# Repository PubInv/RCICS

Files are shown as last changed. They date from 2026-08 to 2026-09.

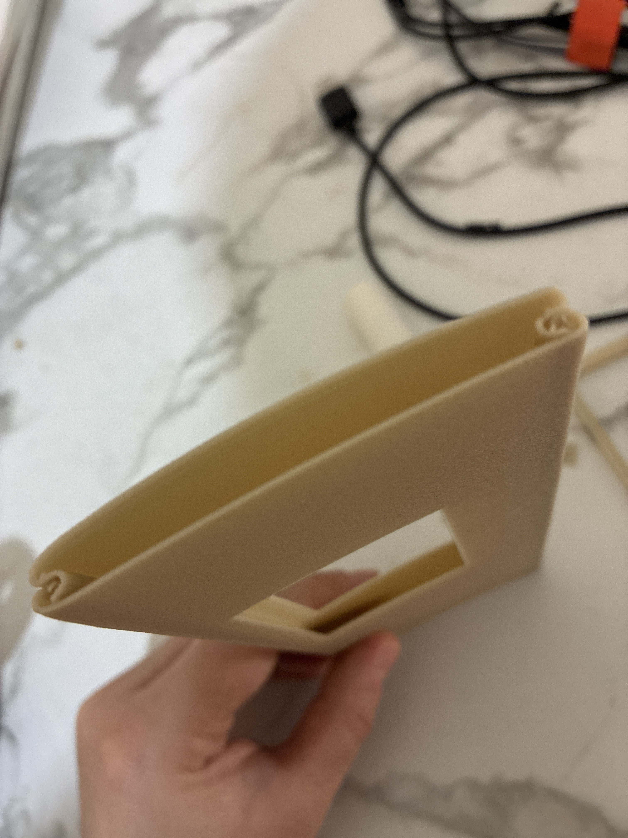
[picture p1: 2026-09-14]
designs/august-2026/CAD/img/print260905/2.jpg

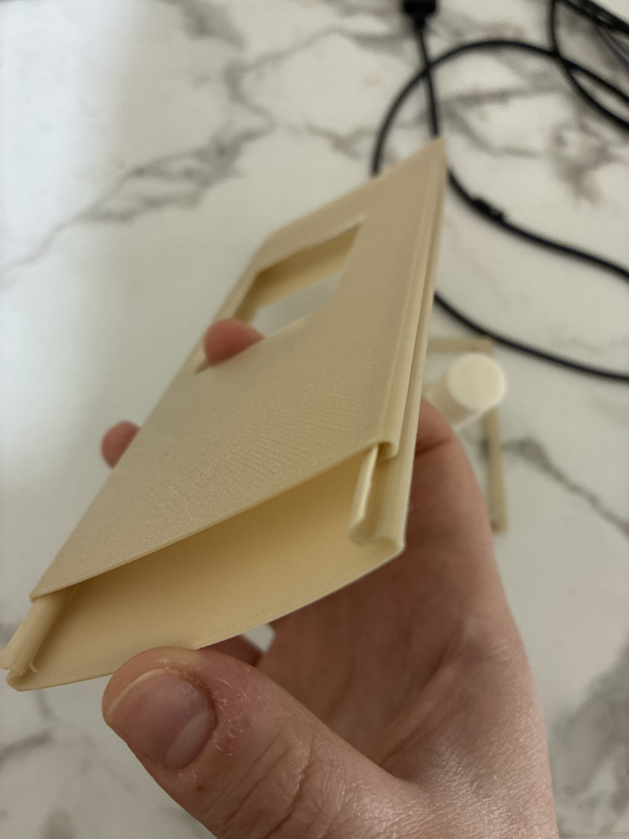
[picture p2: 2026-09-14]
designs/august-2026/CAD/img/print260905/IMG_7551.jpg

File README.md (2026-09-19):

# Rapid Contact Isolation Containment System — RCICS

RCICS is an open source effort to develop a locally fabricable
door-replacement assembly for temporary contact/droplet isolation spaces.

> RCICS is not an airborne-isolation or negative-pressure system.
> The current designs have not been validated or approved for clinical use.

## Current development

The active design iteration is:

- [September 2026 design](designs/september-2026/README.md)

## Historical snapshots

- August 2026 concept: `v1.0.0_AugustDesign`
- [August design summary](designs/august-2026/AgustDesignNotes.md)
 
## Project documentation

- [WHO questions](QUESTIONS_WHO.md)
- [Clinical questions](QUESTIONS_CLINICAL.md)
- [Requirements](docs/requirements/)
- [Design decisions](docs/decisions/)
- [Meeting notes](docs/meeting-notes/)
- [Research](docs/research/)

## Contribution workflow

1. Open or select an issue.
2. Create a branch for the change.
3. Update the design and associated documentation.
4. Open a pull request.
5. Obtain technical review before merging.

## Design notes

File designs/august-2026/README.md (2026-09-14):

# RCICS August 2026 Concept Design

> Historical concept-design snapshot. This design has not been validated
> or approved for clinical deployment.

The complete August design snapshot is preserved in the Git tag:

`august-design-v0.1`

This iteration included:

- Repurposed door concept.
- Viewing-panel concept.
- Medical-line pass-through concept.
- PVC material-transfer chamber.
- L-shaped structural support.
- Initial FreeCAD models and technical drawings.
- Scaled components for 3D printing.

## Important limitations

Dimensions and material selections were provisional.

Known unresolved matters included:

- Transfer-chamber diameter.
- Port diameter and clinical allocation.
- Viewing-panel material and thickness.
- Fastener specification.
- Door-construction differences.
- Gasket and sealing details.
- Prototype validation.

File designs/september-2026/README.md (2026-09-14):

# RCICS September 2026 Design

## Status

Active concept-development iteration.

> This design remains unvalidated and is not approved for clinical use.
> RCICS is intended for contact/droplet isolation support and is not an
> airborne-isolation or negative-pressure system.

## Objective

Develop a locally fabricable door assembly incorporating:

- A rigid viewing panel.
- Medical-line pass-through ports.
- A material-transfer chamber.
- Line strain relief.
- Sealable unused openings.
- Non-porous, disinfectant-compatible surfaces.
- Safe entry and emergency egress.

## Starting design direction

- Repurposed door as the assembly base.
- Plexiglas viewing panel.
- L-beam aluminum mounting frame.
- Gasketed panel-to-door interface.
- At least three medical-line pass-through ports.
- Separate material-transfer chamber.
- Replaceable or sealable port inserts.
- Local fabrication using commonly available tools.

## Provisional assumptions

- Three approximately 7 cm line ports.
- Silicone bungs or grommets, subject to availability.
- PVC-based port solution as fallback.
- Metal door preferred for the initial prototype.

## Open decisions

- Final number and diameter of ports.
- Clinical function assigned to each port.
- Plexiglas thickness.
- Transfer-chamber diameter and length.
- Gasket material.
- Fastener type, depth, and spacing.
- Mounting approach for metal and wooden doors.
- Line strain-relief mechanism.
- Prototype-build location.
- Validation procedure.

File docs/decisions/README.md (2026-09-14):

# RCICS Design Decision Log

This directory records important design decisions separately from meeting
notes and informal discussions.

| ID | Decision | Status | Owner |
|---|---|---|---|
| DEC-001 | Final line-port diameter | Open | Technical lead |
| DEC-002 | Transfer-chamber diameter | Open | Technical lead |
| DEC-003 | Viewing-panel thickness | Open | Design team |
| DEC-004 | Port-insert technology | Open | Courtney / field team |
| DEC-005 | Metal versus wooden door details | Open | Design team |

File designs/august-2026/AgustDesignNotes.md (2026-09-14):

# RCICS
Rapid Contact Isolation Containment System (RCICS)

This is an attempt to design a system for Ebola infection containment which can be 
placed inside a door frame to support the Ebola crisis.

This is an offshoot of Michael Min's FlexContain project of Helpful Engineering, which
pre-existed the current Bundibugyo strain outbreak of Ebola in the Congo (and a conatined outbreak in Uganda.)

## Basic Ideas

1. Either shim something into the frame, or modify the door.
2. Create a "port module" which is standardized that can be used in any door-like structure.
3. Create a "tubing module" that goes near the hinge side that puts minimum motion on tubes passing through the door as it is opened or closed.

## The August Design



An initial design what we can call the "August Design" is depicted above. It features:
1. Standard doors with a modular port cut 18" wide and 24" high in the door.
2. A polyethylene sheeting as a view window, preferable "4 mill" (0.004 inches or 0.1016 millimeters), which is widely available.
3. A "transfer chamber" made of 4" PVC tubing with two doors (end caps) which are never opened at the same time. A ["van stone" flange](https://www.pvcfittingsonline.com/blogs/resource-center/all-about-that-flange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) may be an effective way to seal this against the poly sheeting as it pierces it.
4. L-shaped metal bracket is mounted between the bottom bar and the transfer chamber to support the chamber’s weight and reduce mechanical strain. Metal retaining wires pass through the bracket and wrap around the transfer chamber to secure it firmly in place.
5. A medical tubing port with "cross-cut straw holes" and a vertical bend to create a torturous path for droplets. This port is on the hinge side to limit pulling on tubes.
6. Sheeting clamps consisting of rigid aluminum L-shaped beams to compress the poly sheeting against a gasket.
7. A "flange" (or two) which seal the circular holes of the transfer chamber and the tubing port.

Dimensions of the full design:
1. Portal width: 18"
2. Portal height: 24"
3. Transfer chamber diameter: 8" O.D.
4. Transfer chamber length: 18"
5. Medical tubing O.D.: 1"
6. Medical tubing length: 18" (but bent or shaped into strong vertical shape).

## Photos of the Model

On August 29th, 2026, Rob made a 1/8th scale model depicted below based on ideas generated with Nagham, Courtney, and Jack. It is of course imperfect, but approximately accurately:
1. We commend "L"-beam extruded aluminum strips rather that flat bars as shown in the model.
2. The model has no gasket, but one is advised.
3. There is a bracket cut of foamcore holding up the transfer chamber; this would be a metal shelf bracket at scale.
4. The polyethelyne sheet is cut from a food storage baggie; a thicker material would be avisedly used.
5. The 8" PVC in the full-scale design is simulated with 1" PVC.
6. A drinking straw simulates the 1" PVC that forms the "medical tube port" for thin tubes, such as oxygen.
7. The door is to scale, but steel doors would likely be better than wooden doors. If a wooden door is used, it should be covered in plastic sheeting.
8. This model does not discuss the sealing of the "sweep" or the "jam" of the door.

   Note that the window if off-center; it should be placed closer to the hinge side of the door, so that opening and closing the door creates minimal motion of the tubes in the tube port.

This is a view of the "Clean side", where nurses may observe and interact with the patient.
As would be typical, both "doors" of the transfer chamber are closed (these are the PVC caps.)



The infectious/patient side is depicted below. Strips of extruded metal are used to compress the polyethylene
sheeting against a gasket pressed against the door with sheet metal screws drilled through 
the L-beam, gasket, polyethylene, and metal of the door.



A close-up of screws into the metal strip pressing the sheeting against the door (there is no gasket in this model).





A close-up of the "medical tubing port". Note a wire (brown cord) can be use for strain relief. This tube is intentional "bent" or curved so that droplets have to go upward against gravity to get through the tube. (This tube will also have "cross-cut straw holes" to mostly block fluid droplets.)



The Transfer chamber is sealed through the sheeting with a compressing fitting or "flange". In 1" PVC, this is a threaded screw, but in larger sized is would likely be slip-on bushing or bolted "flanges".





A side view, showing the patient side on the left and the clean side on the right.



The transfer chamber has two caps or "doors". These are simple PVC camps with a retaining wire, so that 
when they are removed the don't fall onto the floor.



The same retaining method is on the clean side.



Although the two open doors shouldn't be open at the same time, this shows that the chamber is open.



MountingTC






Here's a similar model: https://cdn.who.int/media/docs/default-source/documents/emergencies/initiate-idtm-technical-report_20231016.pdf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

This is a WHO design for an isolation module for containment...it contains all the medical equipment that was passed through, so based on the document, I made a list of every single pass-through required: 

- Respiratory Port: oxygen, ventilator, CPAP, BiPAP, HFNC/HFNO tubing
- Patient Fluid Port: IV infusion, medication, feeding, nasogastric, urinary drainage tubing
- Suction Port: suction tubing for mucus, blood, saliva, phlegm, and other fluids
- Monitoring and Power Port: ECG, SpO2, temperature, EtCO2, blood-pressure cables, power and data cables. 

And at least 1 pass-through opening to transfer large materials, i.e., meals. (As mentioned on GitHub - the transfer chamber). For the ports, it should also be sealable when not in use...and include a securement feature. Based on all of that, I found a few commercial ports that are used for similar reasons, but we have to modify them.

1) 1.20" ID - Ext. Length. Fits or Barrier Thickness Range of 5 1/4"-7 1/8". This Unit Provides a Fully Dressed Opening Completely or Barrier. (https://www.amazon.ae/Wall-Cable-Pass-Through-Port/dp/B07SVL5D3T) - It's around 25 dollars. 
2) BulkHead Male Connector: https://www.krelson.com/products/bulkhead-male-connector/
[Bulkhead male connectors pass instrumentation tubing through panels, walls, enclosures, or pressure boundaries while maintaining a sealed penetration point.] Moreover, it specifically mentions "Hazardous area enclosure boundary crossings" - around 3 dollars.
3) ATLAS Scientific BulkHead: The Atlas Scientific Bulkhead provides a reliable and watertight connection point in plumbing systems, ensuring secure passage for tubing through container/tank walls or barriers. (https://atlas-scientific.com/plumbing/bulkhead/) - around 4 dollars. 

I found a "wall airlock passthrough" which was mentioned in this paper:  Feasibility Assessment of a Novel Isolation Care Tent in Uganda During the 2022 Sudan ebolavirus Outbreak. They used it for the transfer of materials (eg: food) without allowing contamination in or out. Although the average one costs around 2k dollars...I did find some alternatives - we could use this: https://wiskindcleanroom.en.made-in-china.com/product/PBmEgLnAmNYu/China-Cleanroom-Integrated-Supplier-Air-Lock-Interloack-Pass-Box-for-Pharm-Plant.html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 - this is the cheapest transfer hacht that I could find (30 dollars apprx)...

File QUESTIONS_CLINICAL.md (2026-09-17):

Question to ask clincal staff

Q1. Importance of a transfer chamber/ hatch? 

Q2. how often would full patient interaction be required & Which minimum patient-care functions must cross the barrier, and which functions should remain inside the patient area?

Q3. what daily/ hourly tasks are required?

Q4. where will the equipment get power from ?

Q5. what problem will the door solve?

Q6.	Which door types, dimensions, fire-safety requirements, emergency-egress requirements, and local fabrication capabilities must the system support?

Q7.	Which cleaning agents and infection-prevention procedures are mandatory in the intended setting?

Q8.	What level of containment performance must be demonstrated, which test methods should be used, and which authority should approve the acceptance criteria?

Q9. Should the transfer chamber incorporate a mechanical interlock to prevent both closures from being opened simultaneously, or could a procedural control be acceptable during early feasibility testing?
 
Q10. Which medical tubing, cables, connectors, and equipment must pass through the barrier?

Q11. How should unused tubing-port capacity be closed and sealed?

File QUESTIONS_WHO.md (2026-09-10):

# Questions for the WHO/ Stakeholders 
1. Should the design retrofit an existing door or door frame, or may a new door be procured and modified?
2. Which minimum patient-care functions must cross the barrier, and which functions should remain inside the patient area?
3.	Which door types, dimensions, fire-safety requirements, emergency-egress requirements, and local fabrication capabilities must the system support?
4.	Which cleaning agents and infection-prevention procedures are mandatory in the intended setting?
5.	What level of containment performance must be demonstrated, which test methods should be used, and which authority should approve the acceptance criteria?
6. Should the transfer chamber incorporate a mechanical interlock to prevent both closures from being opened simultaneously, or could a procedural control be acceptable during early feasibility testing?
7. Which medical tubing, cables, connectors, and equipment must pass through the barrier?
8. How should unused tubing-port capacity be closed and sealed?

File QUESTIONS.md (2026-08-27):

# Questions for the WHO

1. Rather than building a frame into the door, can we purchase new doors and modify them?

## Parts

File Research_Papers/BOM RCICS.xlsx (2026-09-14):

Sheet: BOM AUGUST
Bill of Materials
Assembly Name: Rapid Contact Isolation Containment System (RCICS) |  |  |  |  | [42]
Name | Link | Color | Qty | Picture | Cost | Total Cost = Cost * Qty | Comments
Door | https://www.amazon.ae/SILTOX-Wooden-Interior-Door-200cm/dp/B0GNGJKW6G?mcid=6bb385e861693232b52997da948abe87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 | Brown | 1 |  | $95.00 | $95.00
Polyethylene Sheet | https://ibeam.ae/product/polyethylene-sheet/ | Semi-Transperent | 1 |  | $8.00 | $8.00
4" PVC tubing | https://www.fepy.com/upvc-pipe-uv-resistance-and-noise-reduction-3-inch-x-4-mtr-2?gad_source=1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 | Black | 1 |  | $11.00 | $11.00
Van stone flange | https://www.google.com/search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 | Black | 1 |  | $8.00 | $8.00
Aluminum L-shaped beam | https://www.thomann.ae/adam_hall_6105.htm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 | Gray | 2 |  | $4.00 | $8.00
Metal retaining wires | https://www.thomann.ae/reutlinger_steel_wire_150cm_15mm_loop.htm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 | Gray | 2 |  | $3.80 | $7.60
L-shaped metal bracket | https://www.thomann.ae/adam_hall_40402_l_corner_25_x_37.htm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 | Gray | 1 |  | $0.34 | $0.34
Gasket | https://www.noon.com/uae-en/knp-rubber-gasket-seal-4-inch-is-a-high-quality-sealing-component-designed-to-provide-a-secure-leak-proof-seal-for-various-applica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 | Black | 1 |  | $11.00 | $11.00
Flange | https://www.temu.com/ul/kuiper/un9.html?subj=goods-un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 | Stainless Steel - Gray | 2 |  | $4.00 | $8.00
1" PVC, 4" and 1" caps, strain relief mechanism |  |  | 12 |  | $145.14 | $156.94

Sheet: BOM SEPTEMBER
Bill of Materials
Assembly Name: Rapid Contact Isolation Containment System (RCICS) |  |  |  |  | [42]
Name | Link | Color | Qty | Picture | Cost | Total Cost = Cost * Qty | Comments
Door | https://www.amazon.ae/SILTOX-Wooden-Interior-Door-200cm/dp/B0GNGJKW6G?mcid=6bb385e861693232b52997da948abe87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 | Brown | 1 |  | $95.00 | $95.00
Polyethylene Sheet | https://ibeam.ae/product/polyethylene-sheet/ | Semi-Transperent | 1 |  | $8.00 | $8.00
4" PVC tubing | https://www.fepy.com/upvc-pipe-uv-resistance-and-noise-reduction-3-inch-x-4-mtr-2?gad_source=1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 | Black | 1 |  | $11.00 | $11.00
Van stone flange | https://www.google.com/search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 | Black | 1 |  | $8.00 | $8.00
Aluminum L-shaped beam | https://www.thomann.ae/adam_hall_6105.htm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 | Gray | 2 |  | $4.00 | $8.00
Metal retaining wires | https://www.thomann.ae/reutlinger_steel_wire_150cm_15mm_loop.htm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 | Gray | 2 |  | $3.80 | $7.60
L-shaped metal bracket | https://www.thomann.ae/adam_hall_40402_l_corner_25_x_37.htm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 | Gray | 1 |  | $0.34 | $0.34
Gasket | https://www.noon.com/uae-en/knp-rubber-gasket-seal-4-inch-is-a-high-quality-sealing-component-designed-to-provide-a-secure-leak-proof-seal-for-various-applica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 | Black | 1 |  | $11.00 | $11.00
Flange | https://www.temu.com/ul/kuiper/un9.html?subj=goods-un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 | Stainless Steel - Gray | 2 |  | $4.00 | $8.00
1" PVC, 4" and 1" caps, strain relief mechanism |  |  | 12 |  | $145.14 | $156.94

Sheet: ©
Bill of Materials Template
By Vertex42.com
https://www.vertex42.com/ExcelTemplates/bill-of-materials.html
© 2012-2019 Vertex42 LLC
This spreadsheet, including all worksheets and associated content is a copyrighted work under the United States and other copyright laws.
Do not submit copies or modifications of this template to any website or online template gallery.
Please review the following license agreement to learn how you may or may not use this template. Thank you.
License Agreement
https://www.vertex42.com/licensing/EULA_privateuse.html
Do not delete this worksheet.

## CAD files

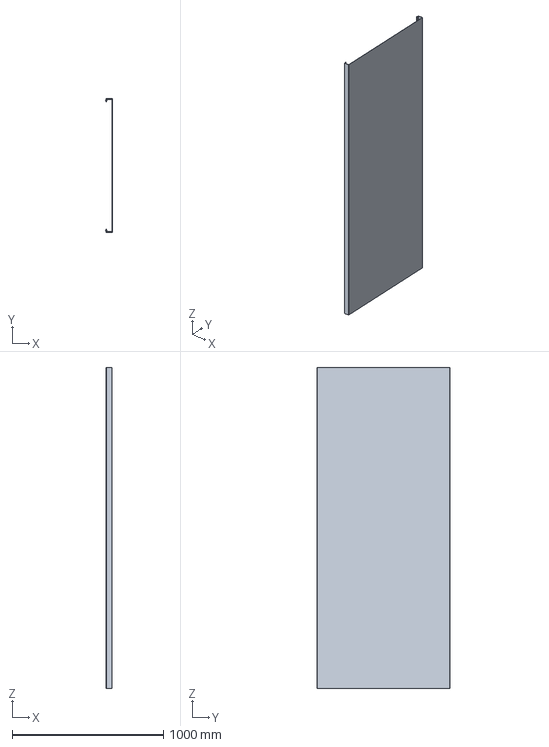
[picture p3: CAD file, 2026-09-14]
designs/august-2026/CAD/ASM.FCStd
43.0 x 883.0 x 2125.0 mm

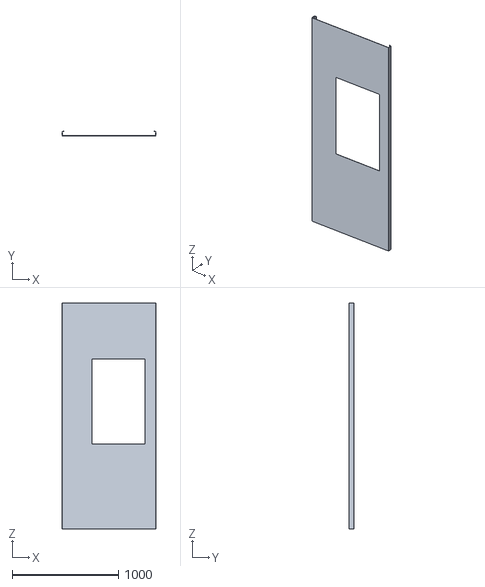
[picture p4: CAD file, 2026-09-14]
designs/september-2026/CAD/stl/asm-Assemblypanel.stl
883.0 x 43.0 x 2125.0

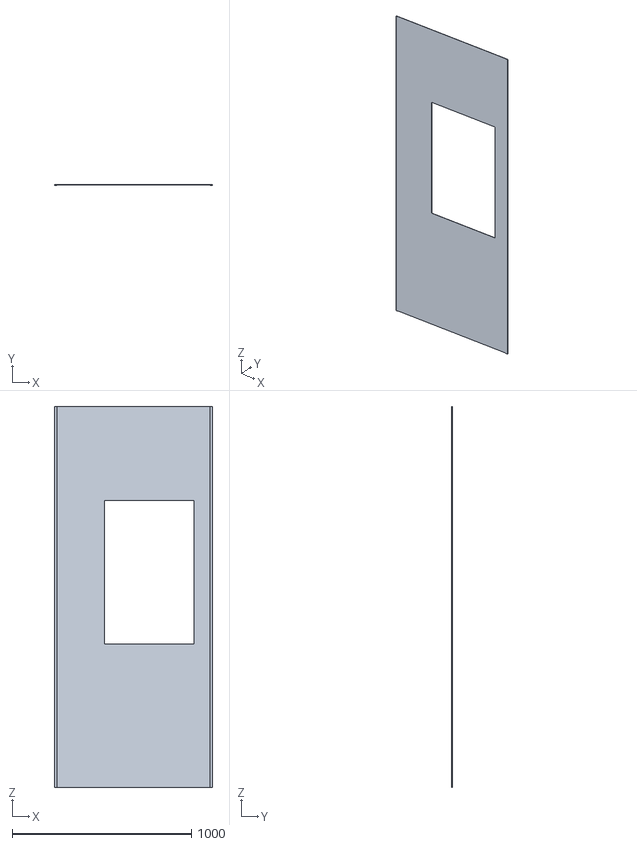
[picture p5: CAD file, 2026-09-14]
designs/september-2026/CAD/stl/asm-Assemblycover.stl
883.0 x 5.00 x 2123.0

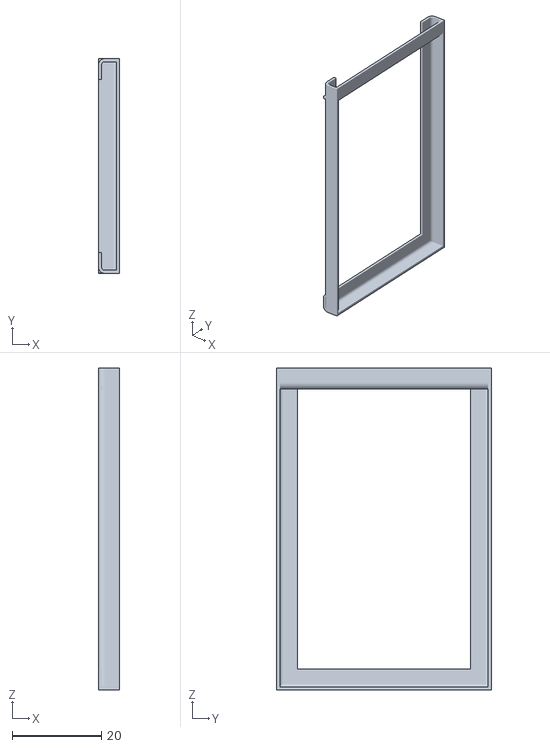
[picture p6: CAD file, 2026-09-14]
designs/september-2026/CAD/stl/scaled to 3dprint/scaled_frame_subAsm-Assembly_scaled.stl
4.70 x 48.0 x 72.1

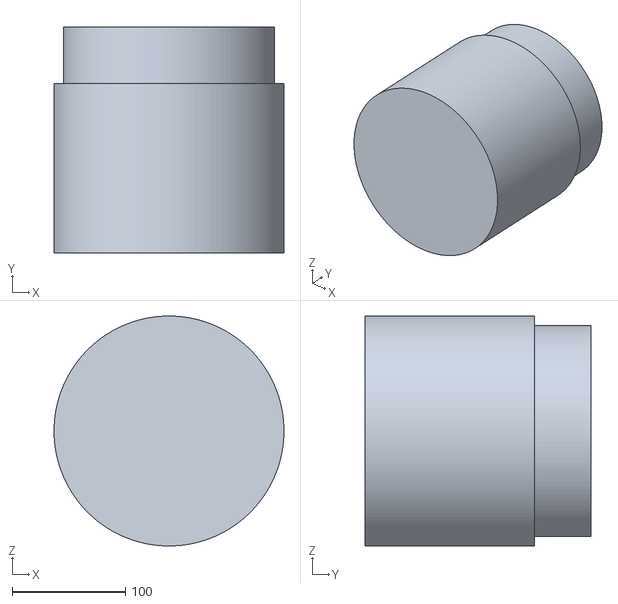
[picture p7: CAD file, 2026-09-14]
designs/september-2026/CAD/stl/asm-Assemblypipe__cover.stl
203.2 x 200.0 x 203.1

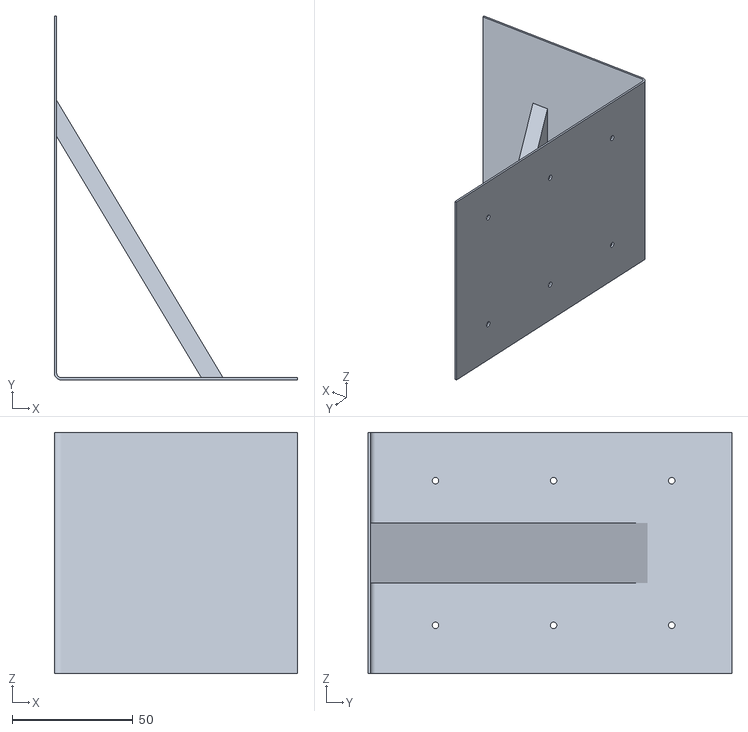
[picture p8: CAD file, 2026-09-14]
designs/september-2026/CAD/stl/Lsupport-Lsupport_wHoles.stl
101.0 x 151.0 x 100.0

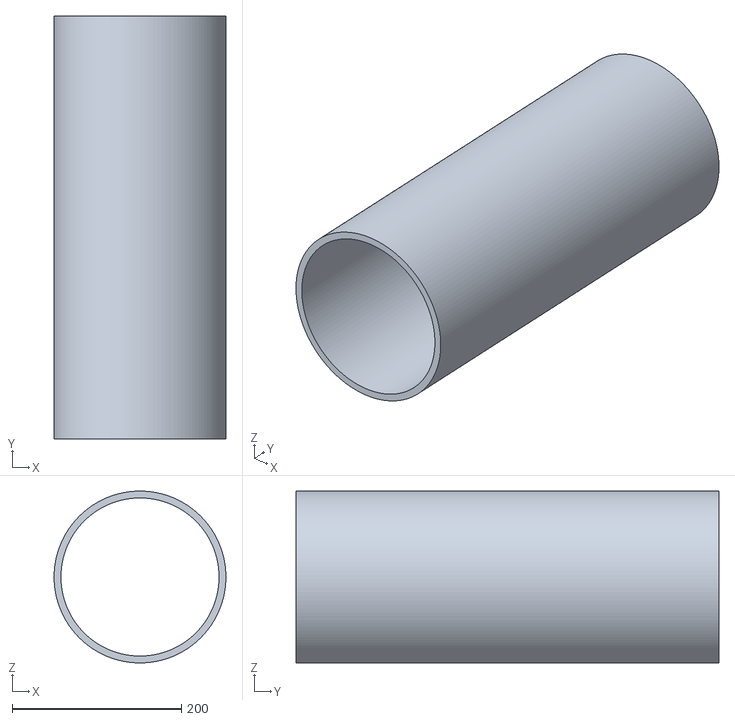
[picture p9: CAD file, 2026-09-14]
designs/september-2026/CAD/stl/asm-Assemblypipe.stl
203.1 x 500.0 x 203.2

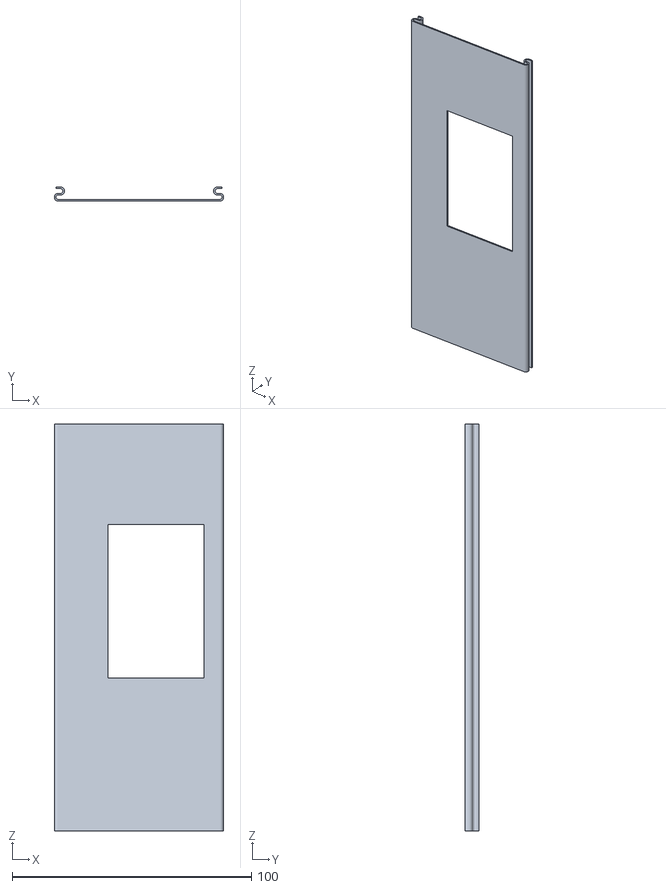
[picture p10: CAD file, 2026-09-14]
designs/september-2026/CAD/stl/scaled to 3dprint/Panel-ExtrudedCutout001_scaled.stl
70.6 x 5.86 x 170.0

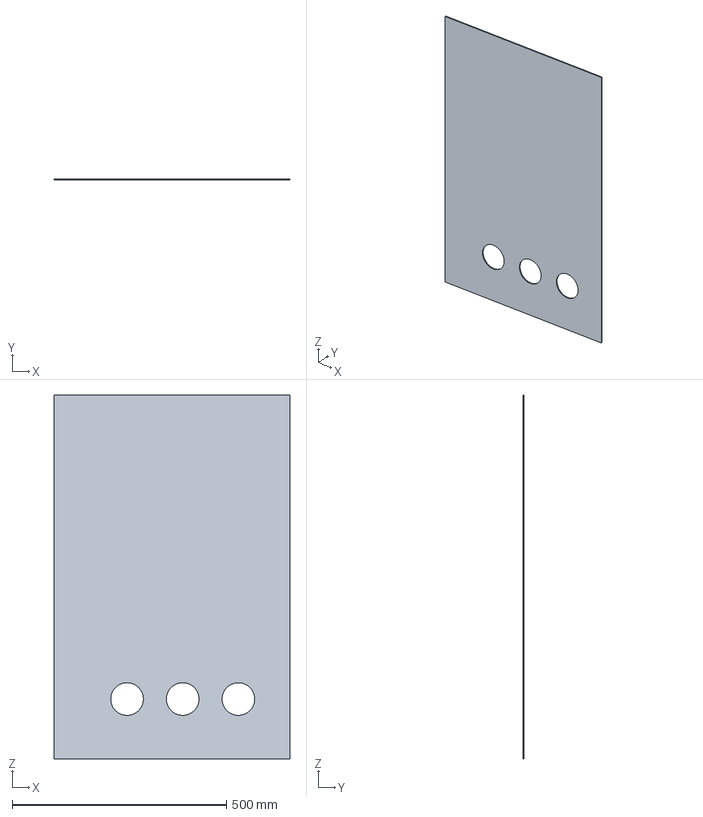
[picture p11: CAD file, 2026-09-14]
designs/september-2026/CAD/PARTS/plexiglass.FCStd
550.0 x 3.00 x 850.0 mm

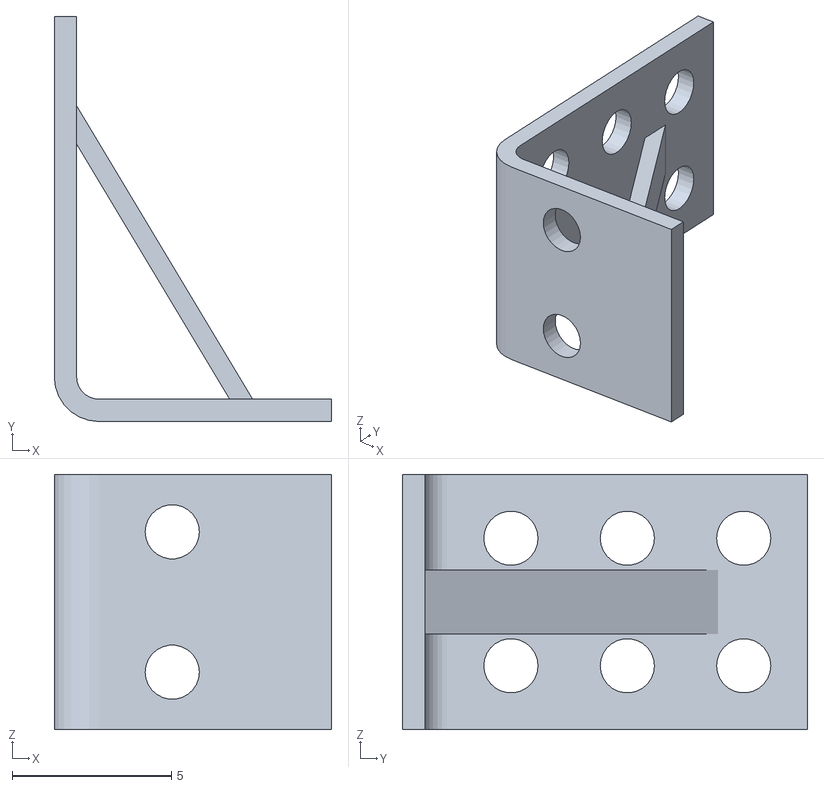
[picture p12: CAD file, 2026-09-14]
designs/september-2026/CAD/stl/scaled to 3dprint/Lsupport-Lsupport_scaled.stl
8.70 x 12.7 x 8.00

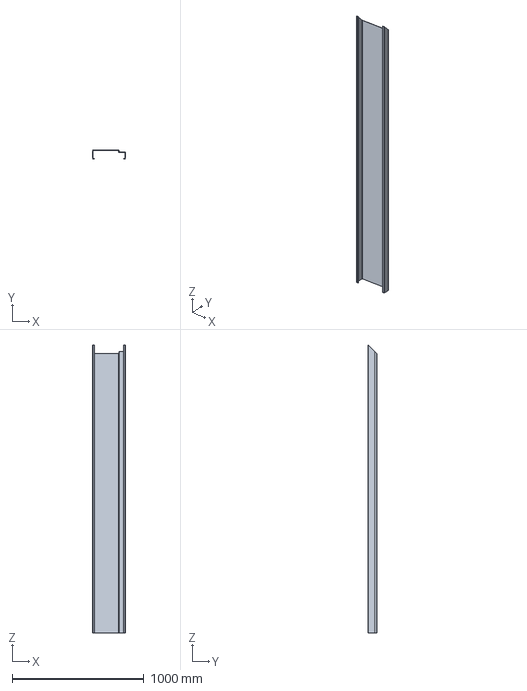
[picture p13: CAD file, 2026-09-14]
designs/september-2026/CAD/PARTS/L_frame.FCStd
250.0 x 66.0 x 2187.5 mm

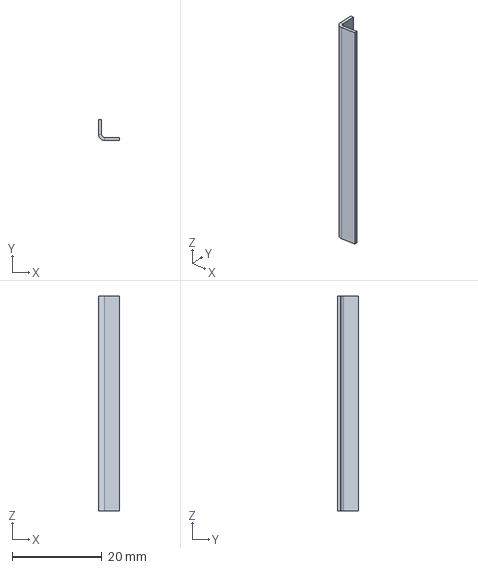
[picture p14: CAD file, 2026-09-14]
designs/september-2026/CAD/PARTS/scaled to 3dprint/Lshape2_scaled.FCStd
4.70 x 4.70 x 48.0 mm

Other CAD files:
designs/september-2026/CAD/asm.FCStd
designs/september-2026/CAD/PARTS/scaled to 3dprint/scaled_frame_subAsm.FCStd
designs/august-2026/CAD/PARTS/Panel.FCStd
designs/september-2026/CAD/PARTS/Panel.FCStd
designs/september-2026/CAD/stl/Lsupport-Lsupport.stl
designs/september-2026/CAD/PARTS/scaled to 3dprint/Panel_scaled.FCStd
designs/august-2026/CAD/asm.FCStd
designs/september-2026/CAD/PARTS/Lshap2.FCStd
designs/september-2026/CAD/PARTS/Lshape1.FCStd
designs/september-2026/CAD/PARTS/Lshape2.FCStd
designs/september-2026/CAD/PARTS/R_frame.FCStd
designs/september-2026/CAD/PARTS/T_frame.FCStd
designs/september-2026/CAD/PARTS/cover.FCStd
designs/september-2026/CAD/PARTS/scaled to 3dprint/Lshape1_scaled.FCStd
designs/september-2026/CAD/PARTS/scaled to 3dprint/Lsupport_scaled.FCStd
designs/september-2026/CAD/PARTS/scaled to 3dprint/cover_scaled.FCStd
designs/september-2026/CAD/stl/Frame.stl
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

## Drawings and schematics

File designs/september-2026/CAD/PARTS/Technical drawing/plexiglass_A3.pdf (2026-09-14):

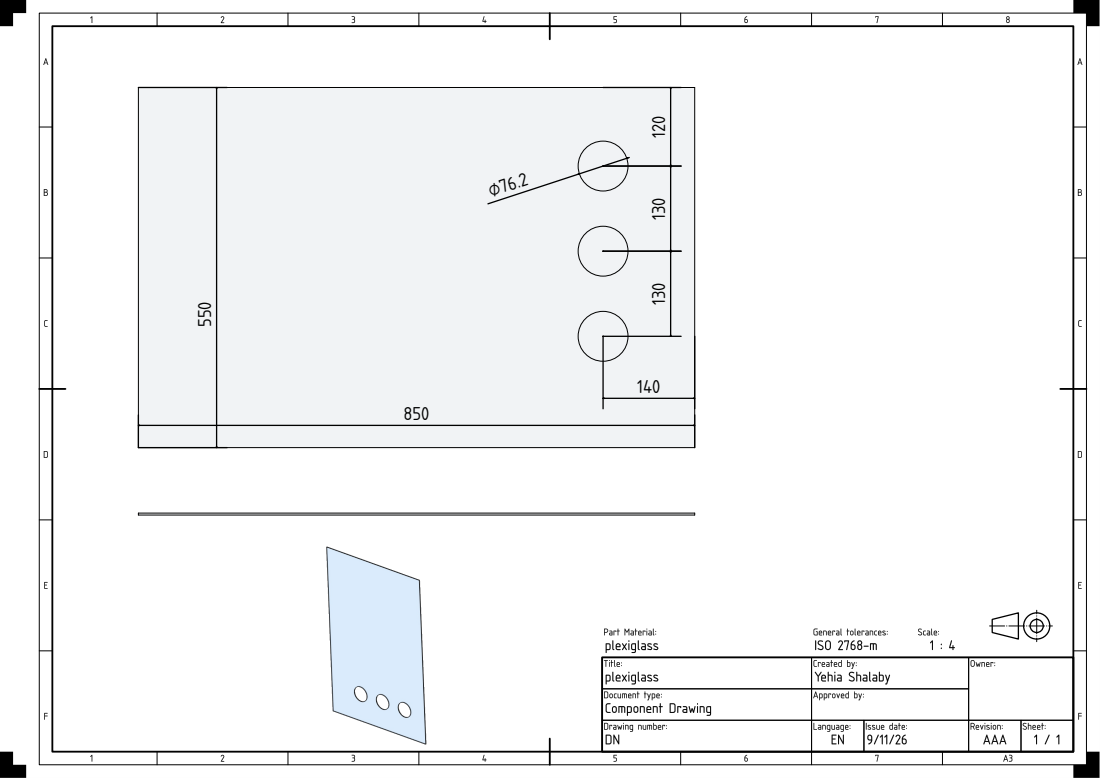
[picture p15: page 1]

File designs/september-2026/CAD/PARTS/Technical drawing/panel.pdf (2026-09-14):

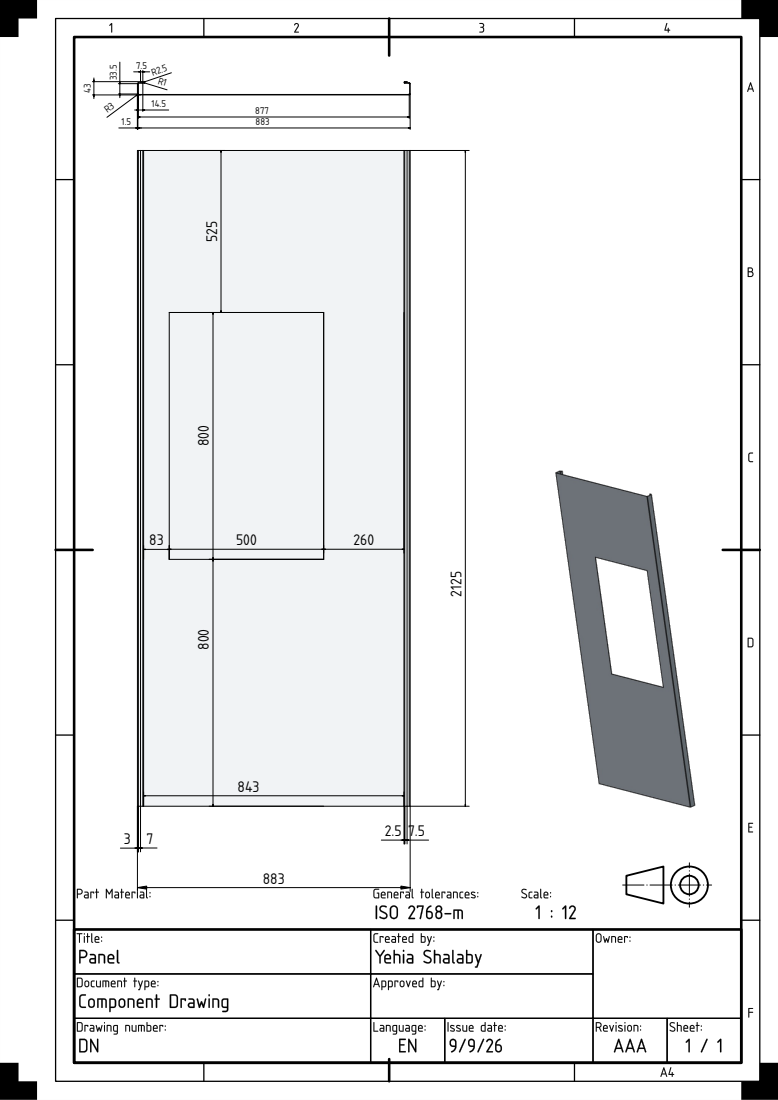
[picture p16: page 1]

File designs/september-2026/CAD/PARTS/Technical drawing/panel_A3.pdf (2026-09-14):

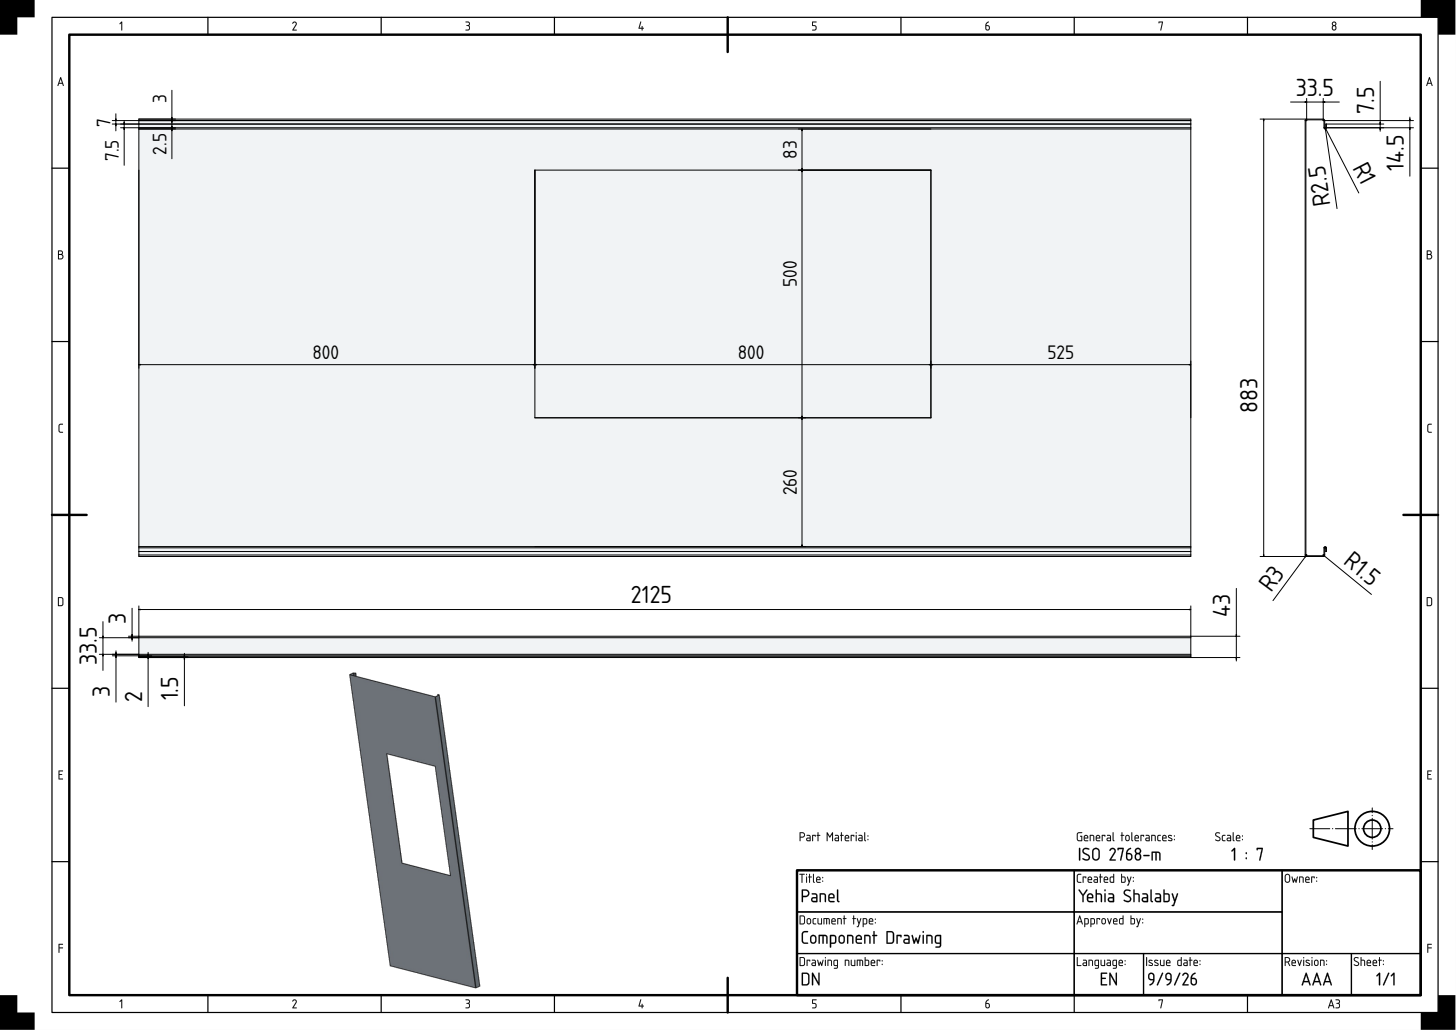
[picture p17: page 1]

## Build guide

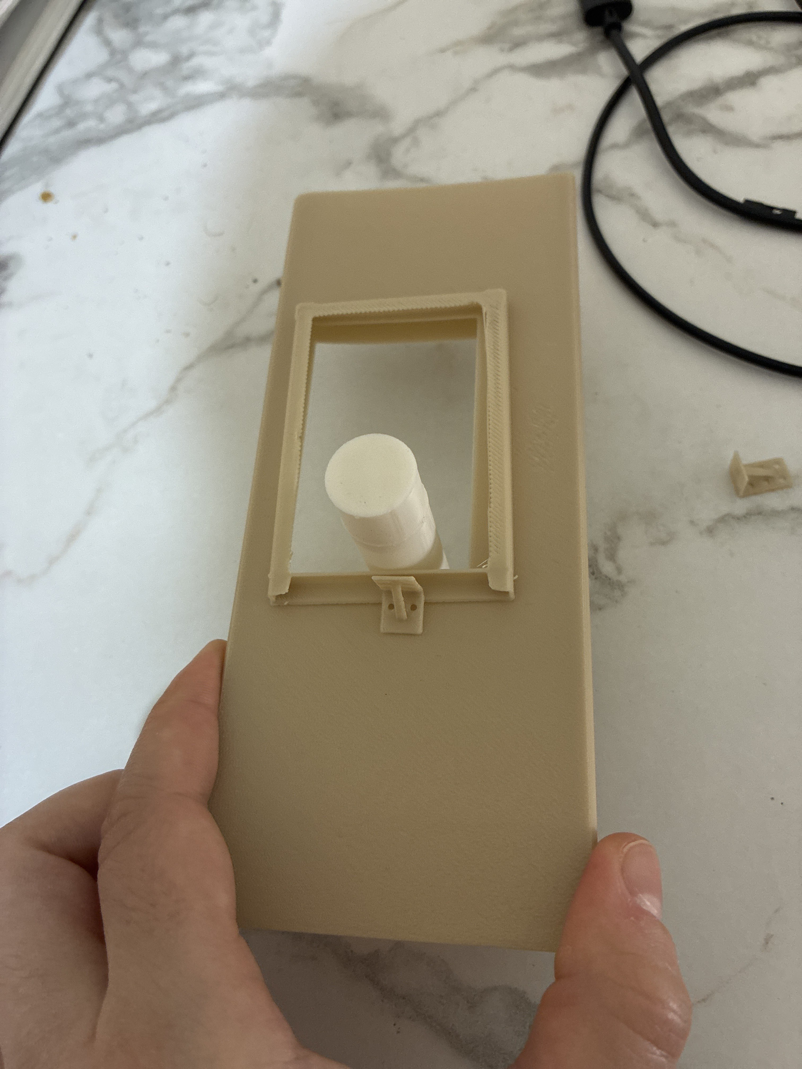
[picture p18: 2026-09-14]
designs/august-2026/CAD/img/print260905/IMG_7550.jpg

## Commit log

2026-08-30 Revise transfer chamber support details in README
    Updated the description of the transfer chamber support mechanism in the README.
2026-08-30 Add image for supporting the transfer chamber design in README
2026-08-30 Enhance README with isolation module design details
    Added detailed information about isolation module design and pass-through requirements, including links to commercial products and alternatives for material transfer.
2026-09-02 mkaing frame parts with assembly file
    [ASM.FCStd, L_frame.FCStd, R_frame.FCStd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]
2026-09-03 create the door panal
    [Panel.FCStd]
2026-09-03 add the panel to the assembly
    [ASM.FCStd, T_frame.FCStd]
2026-09-03 create the door cover and add to the asmmebly
    [ASM.FCStd]
2026-09-03 add door cover
    [cover.FCStd]
2026-09-04 make open for the portal and creat the steel frame for it and the portal parts
    [ASM.FCStd, Lshap2.FCStd, Lshape1.FCStd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]
2026-09-04 add portal to asm.FCStd
    [asm.FCStd, pipe.FCStd, pipe_cover.FCStd]
2026-09-05 creat L support under the portal chamber and add to the assembly file asm
    [Lsupport.FCStd, asm.FCStd]
2026-09-05 export stl files for 3d printing
    [Frame.stl, Lsupport-Lsupport.stl, asm-Assemblycover.stl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]
2026-09-05 add m3 self threaded holes to the L shape support
    [Lsupport-Lsupport_wHoles.stl, Lsupport.FCStd]
2026-09-05 scaling down the parts for 3d printing with the thikness of 0.7mm
    [Lsupport-Lsupport_scaled.stl, Lsupport_scaled.FCStd, Panel-ExtrudedCutout001_scaled.stl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]
2026-09-05 scaling down the frame for 3d printing with the thikness of 0.7mm
    [Lshape1_scaled.FCStd, Lshape2_scaled.FCStd, scaled_frame_subAsm-Assembly_scaled.stl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]
2026-09-09 testign export techinal drawing for chamber and door panel
    [Lshape1.FCStd, Lshape2.FCStd, Lsupport.FCStd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]
2026-09-09 add A3 pages for chamber and panel
    [Panel.FCStd, pipe.FCStd]
2026-09-10 Revise questions for WHO stakeholders and update title
    Updated the title and added several questions for stakeholders regarding door design and patient-care functions.
    Questions added from Nagham Report
2026-09-10 Enhance clinical questions for transfer chamber assessment
    Expanded questions for clinical staff regarding transfer chamber requirements and safety protocols.
    Questions from nagham report
2026-09-11 Hide the 8in chamber and add plexiglass with 3in three ports
    [Lshape2.FCStd, Panel.FCStd, Upipe.FCStd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]
2026-09-12 add pdf extention for the technical drawings
    [Lshape1.FCStd, Lshape2.FCStd, Lsupport.FCStd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]
2026-09-14 august design
    [Panel.FCStd, asm.FCStd, pipe.FCStd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]
2026-09-14 Add missing file to August design archive
    [BOM RCICS.xlsx]
2026-09-14 Move inherited CAD into September design workspace
2026-09-14 fix parts files
    [L_frame.FCStd, Lshape1.FCStd, Lshape1_scaled.FCStd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]
2026-09-14 clean up files at september-2026 folder
    [ASM.FCStd, Frame.stl, L_frame.FCStd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]
2026-09-17 Expand clinical questions for transfer chamber evaluation
    Added additional questions for clinical staff regarding transfer chamber requirements and procedures.
